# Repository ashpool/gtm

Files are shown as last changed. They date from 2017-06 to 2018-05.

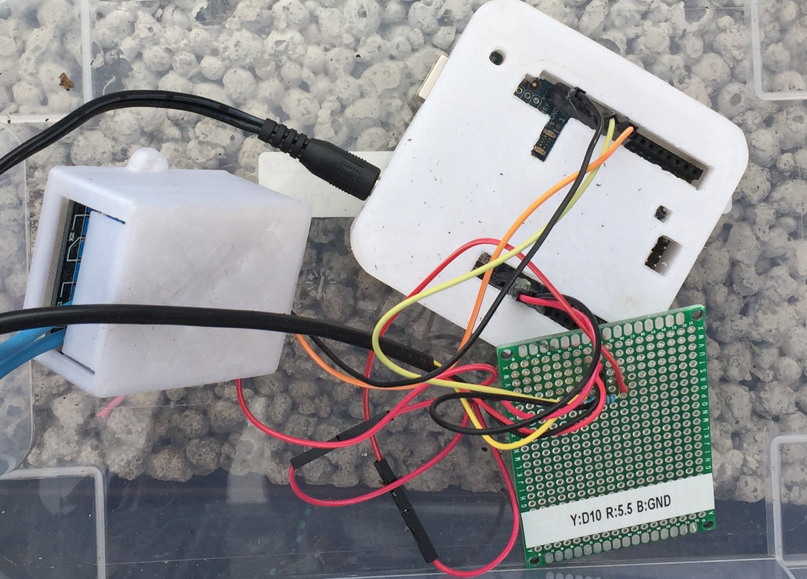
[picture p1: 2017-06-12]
docs/frankenmonster.png

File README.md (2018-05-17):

# General Temperature Machine

When incubating eggs and brewing beer, keeping a greenhouse cool, and countless other applications, it's desirable to maintain a constant temperature. A naive (and in many cases fully workable solution) is to use a thermostat, a device that turns on a heatsource or a cooler at a set temperature and turns it off when the temperature is correct. Using this method will cause the temperature to vary, or oscillate, to some degree, due to inertia in the system. I wanted to achive a near constant temperature, so I applied the PID algorithm.

> A proportional–integral–derivative controller (PID controller) is a control loop feedback mechanism (controller) commonly used in industrial control systems. A PID controller continuously calculates an error value as the difference between a desired setpoint and a measured process variable. The controller attempts to minimize the error over time by adjustment of a control variable, such as the position of a control valve, a damper, or the power supplied to a heating element, to a new value determined by a weighted sum..."
 ~[Wikipedia](https://en.wikipedia.org/wiki/PID_controller)

The PID in this case is not designed to output an analog value, since the relay can only be on or off, instead it outputs how long the heater or cooler should be on within a fixed interval. It's essentially a really slow version of pulse width modulation.

The hardware needed is a temperature sensor, a heat source or a cooler, and a controller. In my case I'm using:
* [DS18S20](https://arduino-info.wikispaces.com/Brick-Temperature-DS18B20) temperature sensor.
* [2 way relay module](https://arduino-info.wikispaces.com/RelayIsolation) (although 1 should work just fine).
* An Arduino as controller

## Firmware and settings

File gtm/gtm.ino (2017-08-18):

/* 

PID controller for controlling temperature by either using a heater or a cooler
 
 # Temperature
 OneWire DS18S20, DS18B20, DS1822 Temperature Example

 http://www.pjrc.com/teensy/td_libs_OneWire.html

 The DallasTemperature library can do all this work for you!
 http://milesburton.com/Dallas_Temperature_Control_Library

 # Relay

 Connect 5V on Arduino to VCC on Relay Module
 Connect GND on Arduino to GND on Relay Module
 Connect GND on Arduino to the Common Terminal (middle terminal) on Relay Module.
*/

#include <OneWire.h>
#include <PID_v1.h> // https://github.com/br3ttb/Arduino-PID-Library
#include <Thread.h> // https://github.com/ivanseidel/ArduinoThread
#include <ThreadController.h> // https://github.com/ivanseidel/ArduinoThread
#include <TimerOne.h> // https://github.com/PaulStoffregen/TimerOne
#include <DallasTemperature.h>

#define RELAY_PIN 8   // Connect Digital Pin 8 on Arduino to ? on Relay Module
#define SENSOR_PIN 10
#define DELAY 1000
#define ERROR_RESPONSE -1000
#define ERROR_NO_MORE_ADDRESSES -2000
#define ERROR_CRC_IS_NOT_VALID -3000
#define ERROR_FAILED_TO_RESET -4000

const unsigned long COOLER = 1; 
const unsigned long HEATER = 0; 
const unsigned long TYPE = COOLER; 
const unsigned long WINDOW_SIZE = 100;
const unsigned long PID_INTERVAL = 60000;

unsigned long _windowStartTime;
double _setpoint, _input, _output;
double _kp = 70.0, _ki = 0.6, _kd = 0.6; // Initial tuning parameters
PID _pid(&_input, &_output, &_setpoint, _kp, _ki, _kd, DIRECT);
OneWire _ow(SENSOR_PIN);  // on pin 10 (a 4.7K resistor is necessary)
DallasTemperature _sensors(&_ow); //Tell Dallas Temperature Library to use oneWire Library

class Logger {

  public:
    void errorF(const char* msg, float value){
      Serial.print(msg);
      Serial.println(value);
    }
  
    void info(const char* msg) {
      Serial.println(msg);
    }

    void debug(const char* msg) {
      Serial.println(msg);
    }
  
    void infoF(const char* msg, float value){
      Serial.print(msg);
      Serial.println(value);
    }

    void infoD(const char* msg, double value){
      Serial.print(msg);
      Serial.println(value);
    }
    
    void infoI(const char* msg, unsigned int value){
      Serial.print(msg);
      Serial.println(value);
    }

    void infoL(const char* msg, unsigned int value){
      Serial.print(msg);
      Serial.println(value);
    }
};

Logger Log = Logger();

float getTemp() {
  _sensors.requestTemperatures();
  return _sensors.getTempCByIndex(0);
}

class SensorThread: public Thread {
  public:
    float value;
    int pin;

    void run() {
      value = getTemp();
      runned();
    }
};

ThreadController _controller = ThreadController();

void timerCallback() {
  _controller.run();
}

SensorThread _tempSensor = SensorThread();

void setup(void) {
  delay(1000);
  Serial.begin(9600);
  delay(1000);
  _sensors.begin();
  pinMode(RELAY_PIN, OUTPUT);
  _tempSensor.pin = SENSOR_PIN;
  _tempSensor.setInterval(10000);
  _controller.add(&_tempSensor);
  Timer1.initialize(10000000);
  Timer1.attachInterrupt(timerCallback);
  Timer1.start();
  _windowStartTime = millis();
  _setpoint = 28.0;
  _pid.SetOutputLimits(0, WINDOW_SIZE); //tell the PID to range between 0 and the full window size
  _pid.SetMode(AUTOMATIC); //turn the PID on
}

void loop(void) {
  float tempOrErrow = _tempSensor.value;
  if (tempOrErrow <= ERROR_RESPONSE) {
    Log.errorF("Code: ", tempOrErrow);
    return;
  }
  _windowStartTime = millis();
  _input = tempOrErrow;
  _pid.Compute();
  const float ratio = _output / WINDOW_SIZE;
  const unsigned long runtime = PID_INTERVAL * ratio; 
  Log.infoD("Input: ", _input); 
  Log.infoD("Output: ", _output); 

  Log.infoL("runtime ", runtime);
  digitalWrite(RELAY_PIN, TYPE == HEATER ? LOW : HIGH); 
  Log.infoL("PID_INTERVAL - runtime ", PID_INTERVAL - runtime); 
  while (millis() - _windowStartTime < runtime);
  digitalWrite(RELAY_PIN, TYPE == HEATER ? HIGH : LOW);
  
  while (millis() - _windowStartTime < PID_INTERVAL);
}

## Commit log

2016-08-16 First PID implementaton
    Remove OneWire files from this repo. Gotta figure out a better way to
    handle dependencies.
2016-08-16 Add Fritzing sketch
    [incuino.fzz]
2016-08-16 Extract temp measurement to a "thread"
    Larger P seems to work better for this rather slow feedback loop.
2017-06-12 Update schematics
    [incuino.fzz]
2018-05-21 Fix relay connections
    [gtm.fzz]
